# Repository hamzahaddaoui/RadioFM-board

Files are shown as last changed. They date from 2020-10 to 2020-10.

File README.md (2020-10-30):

# Radio FM with speaker

## Abstract

In this project I developed a microcontroller based system that transmits a digital audio signal to an amplifier, attached to a speaker.
The audio signal can be received from different sources such as an FM radio module, which picks up various frequencies, or from a 3.5mm jack. Further development may include a bluetooth support.

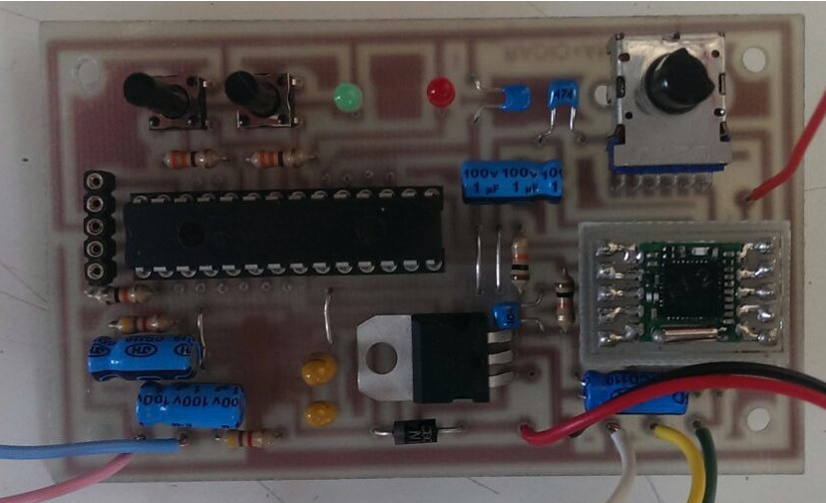
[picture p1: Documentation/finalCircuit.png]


## Details

The project began with a deep study of the TEA5767 chip, and the developing of a library for its usage.
This component is an electronically tuned FM stereo radio for low-voltage applications with fully integrated Intermediate Frequency (IF) selectivity and demodulation. The radio is completely adjustment-free and only requires a minimum of small and low cost external components. The radio can be tuned to the European, US, and Japanese FM bands.

The amplification stage was handled by the PAM8320 which is an efficient 20W mono Class-D audio power amplifier, designed to drive speakers as low as 4Ω in a bridge-tied- load configuration. Due to the low power dissipation and high efficiency of up to 95%, it can be used without any external heat sink whilst playing music.

The microcontroller mounted on the board (8-bit Microchip PIC) controls the user inputs (buttons) and  generates a response to be sent to the radio module. Using the buttons on the top of the speaker, it is possible to change frequency, save favourite stations or go on search mode.

### Schematic 
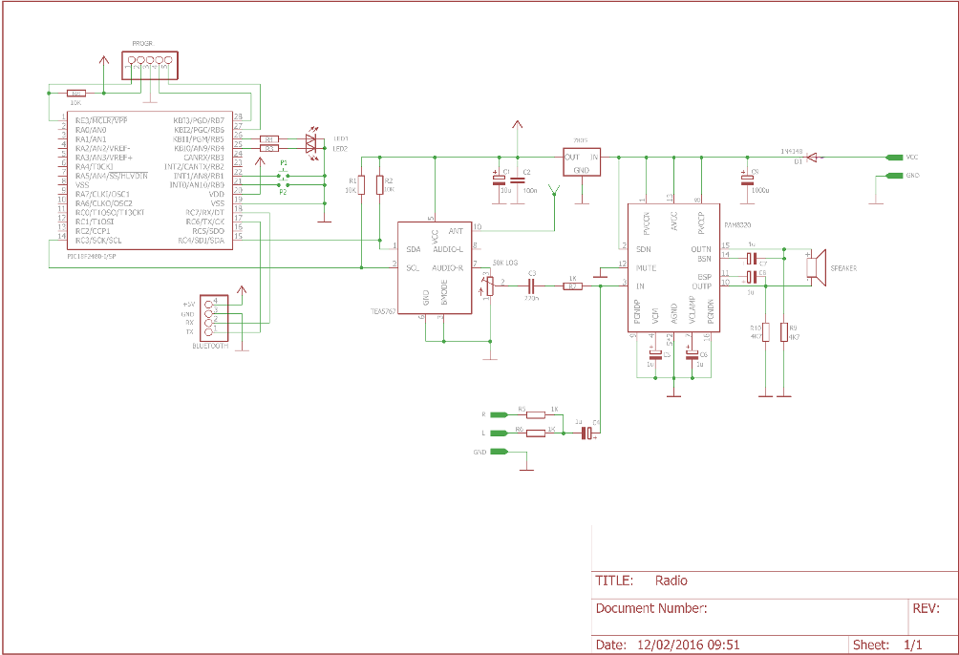
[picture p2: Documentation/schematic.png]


### PCB
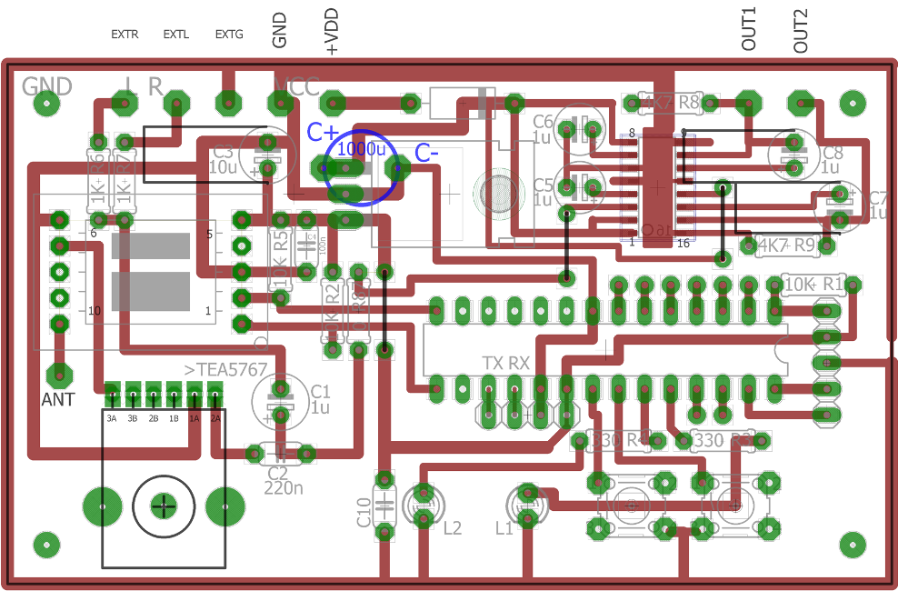
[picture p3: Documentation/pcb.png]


### Board photoengraving process
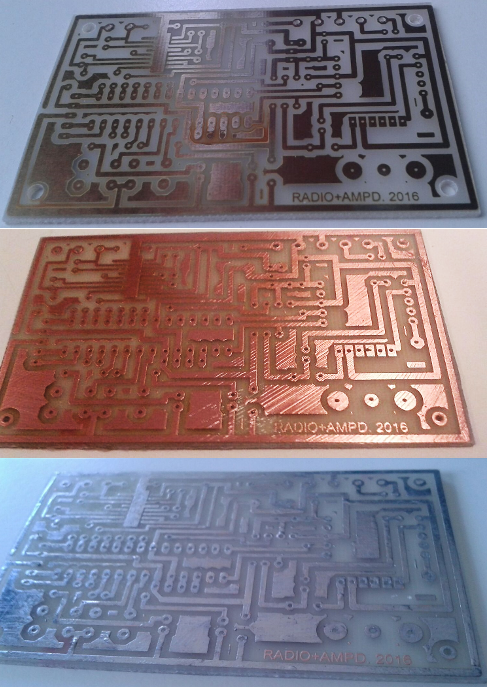
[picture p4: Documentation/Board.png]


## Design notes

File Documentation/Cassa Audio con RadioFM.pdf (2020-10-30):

Cassa Audio con Radio FM

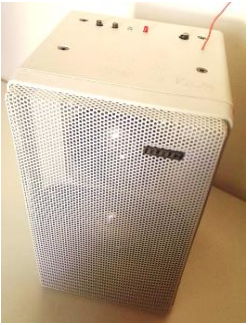
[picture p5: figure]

Hamza Haddaoui | 4ECn | 25/04/16

Hamza Haddaoui
4

a
ECn I.T.I.S. P. Paleocapa
12/02/16

In questo progetto è stato realizzato un dispositivo che permette di amplificare un segnale audio, inviandolo ad una cassa operante in modalità mono.
Il segnale audio, può essere ricevuto da diverse sorgenti quali un modulo radio FM, che provvede a captare frequenze, oppure da un jack 3,5mm.
Il microcontrollore montato sulla scheda, provvede a ricevere gli input, cioè lo stato dei tasti presenti sul pannello superiore, e generare una risposta da inviare al modulo della radio. É possibile cambiare frequenza, o tra quelle salvate oppure in modalità di ricerca.

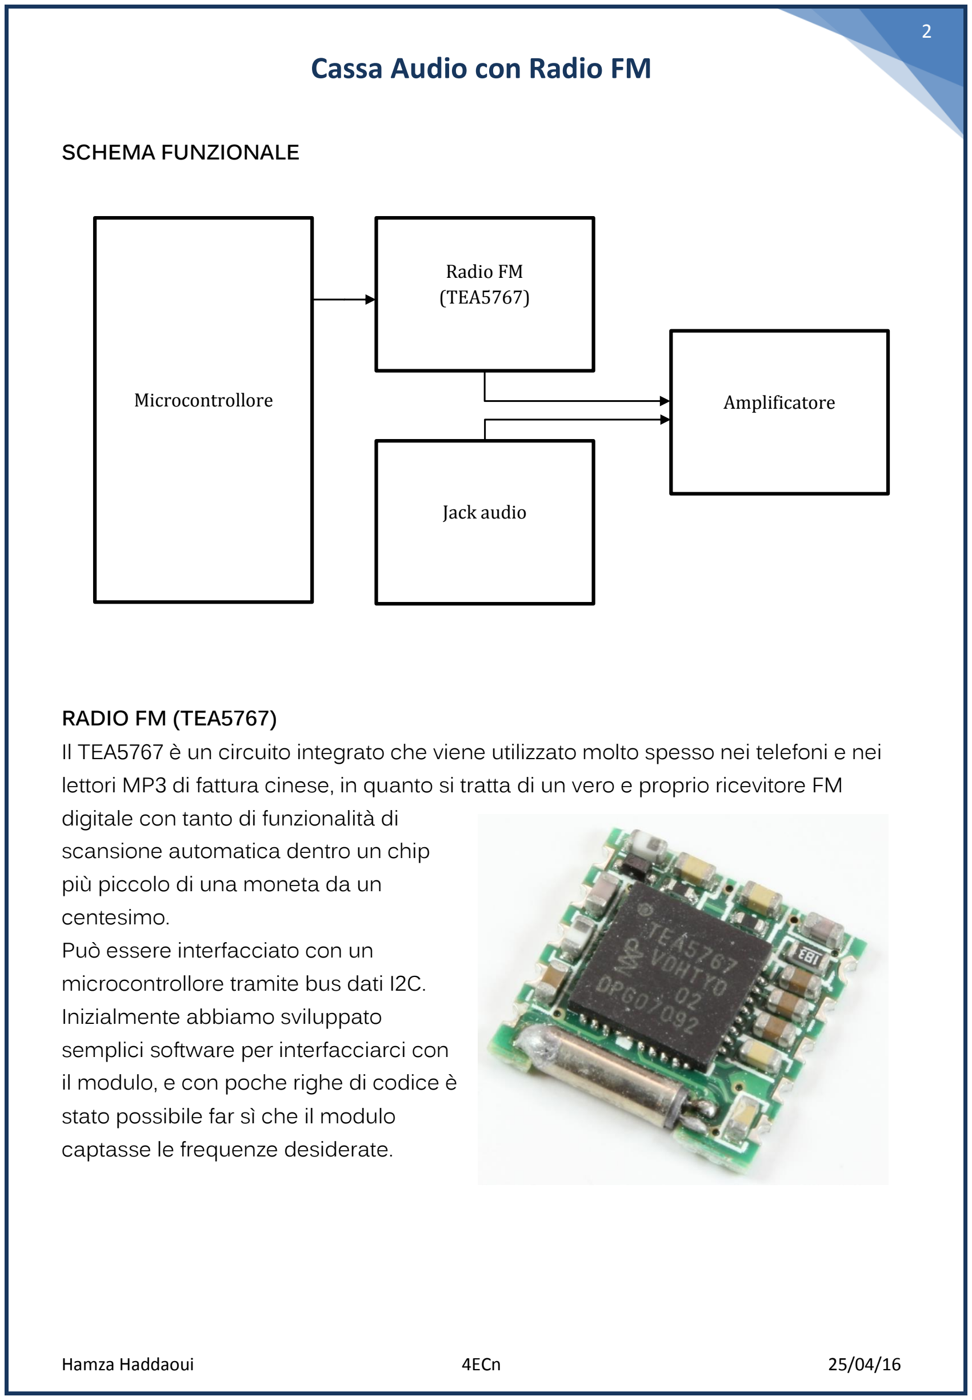
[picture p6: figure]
SCHEMA FUNZIONALE; RADIO FM (TEA5767); digitale con tanto di funzionalità di scansione automatica dentro un chip più piccolo di una moneta da un centesimo. Può essere interfacciato con un microcontrollore tramite bus dati I2C. Inizialmente abbiamo sviluppato semplici software per interfacciarci con; stato possibile far sì che il modulo captasse le frequenze desiderate.; Microcontrollore; Radio FM (TEA5767); Jack audio; Amplificatore

Il TEA5767 è un circuito integrato che viene utilizzato molto spesso nei telefoni e nei lettori MP3 di fattura cinese, in quanto si tratta di un vero e proprio ricevitore FM

il modulo, e con poche righe di codice è

Le funzionalità principali della radio sono:
- Stand-by
- Ricerca automatica
- Signal dependent High Cut Control (HCC)
- Soft mute
- Stereo Noise Cancelling (SNC)
- Informazioni sulla qualità del segnale

Amplificatore (PAM8320)
L’amplificatore è un dispositivo elettronico che varia il segnale in uscita, in funzione di un segnale applicato al suo ingresso al fine di aumentarne la potenza.
Esistono diverse tipologie di amplificatori, che differiscono per qualità di amplificazione, consumo energetico, etc.
Il PAM8320 è un classe D, vale un amplificatore con un’efficienza energetica molto alta (circa 90%) dovuta al fatto che i transistor utilizzati non lavorano mai in zona attiva, ma continuano a commutare da accesi a spenti (sono detti infatti amplificatori a commutazione).
Le caratteristiche principali di questo amplificatore:
Potenza | 20W
Alimentazione | 4.5V – 15V
Impedenza d’uscita | 4 ohm

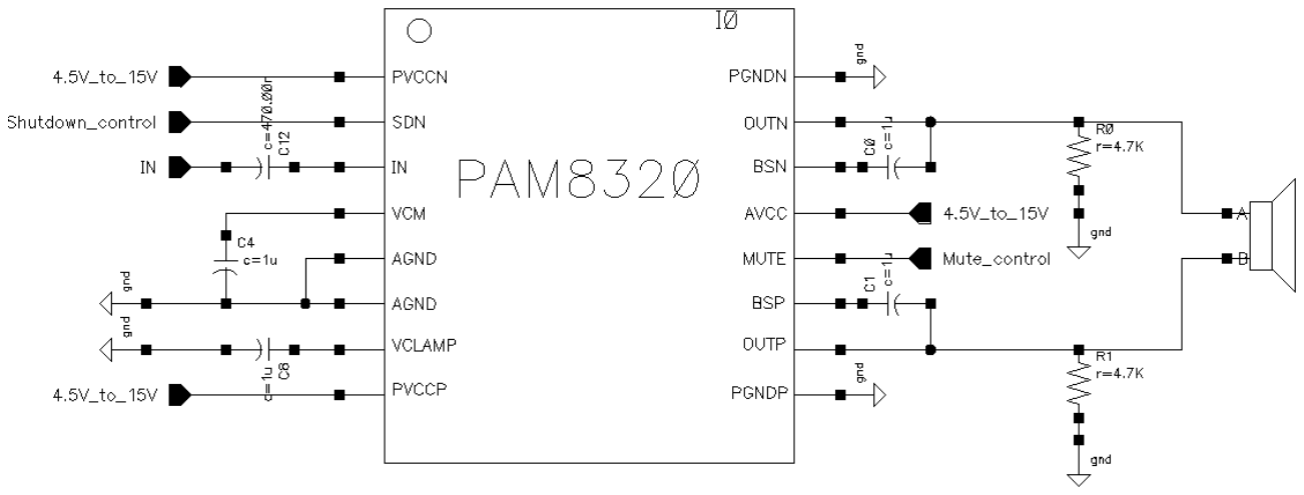
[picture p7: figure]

Fasi di lavoro:
1. Progettazione e realizzazione scheda elettronica
2. Collaudo e programmazione
3. Assemblaggio della cassa audio

PROGETTAZIONE
Nella prima fase, dopo aver studiato i componenti base del progetto (Radio e amplificatore), ci siamo dedicati allo studio dello schema elettrico, e la realizzazione su carta del PCB.
Una volta terminata la parte di disegno,
abbiamo realizzato le schede elettroniche
tramite la tecnica di fotoincisione.
Il punto di partenza, sono state delle basette, interamente ricoperte di rame da un lato, e il disegno del PCB, stampato a grandezza reale su foglio lucido. Mediante l’uso di un bromografo, la basetta viene esposta ai raggi ultravioletti nei punti non coperti dal PCB (vale a dire, dovunque non ci siano piste, piazzole etc.). Dopodiché la basetta viene trattata chimicamente, e vengono eliminati questi punti “ciechi”. Il passaggio successivo è stato quello di eliminare tramite una spazzola abrasiva, tutto il materiale che
copriva il rame, e subito dopo di stagnare
le piste e le piazzole.

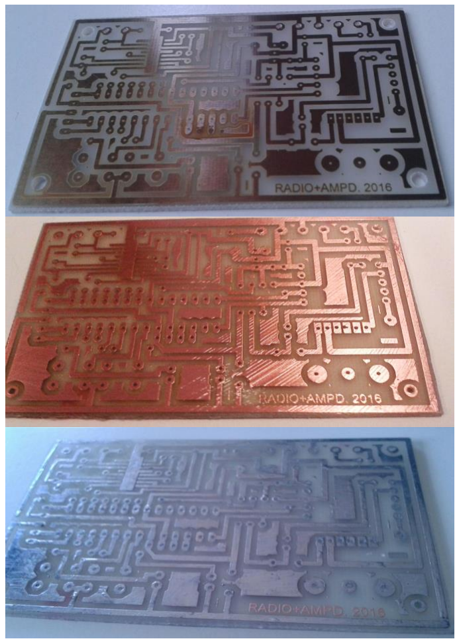
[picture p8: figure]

Una volta fatto ciò, abbiamo montato tutti i componenti, seguendo lo schema fatto precedentemente.

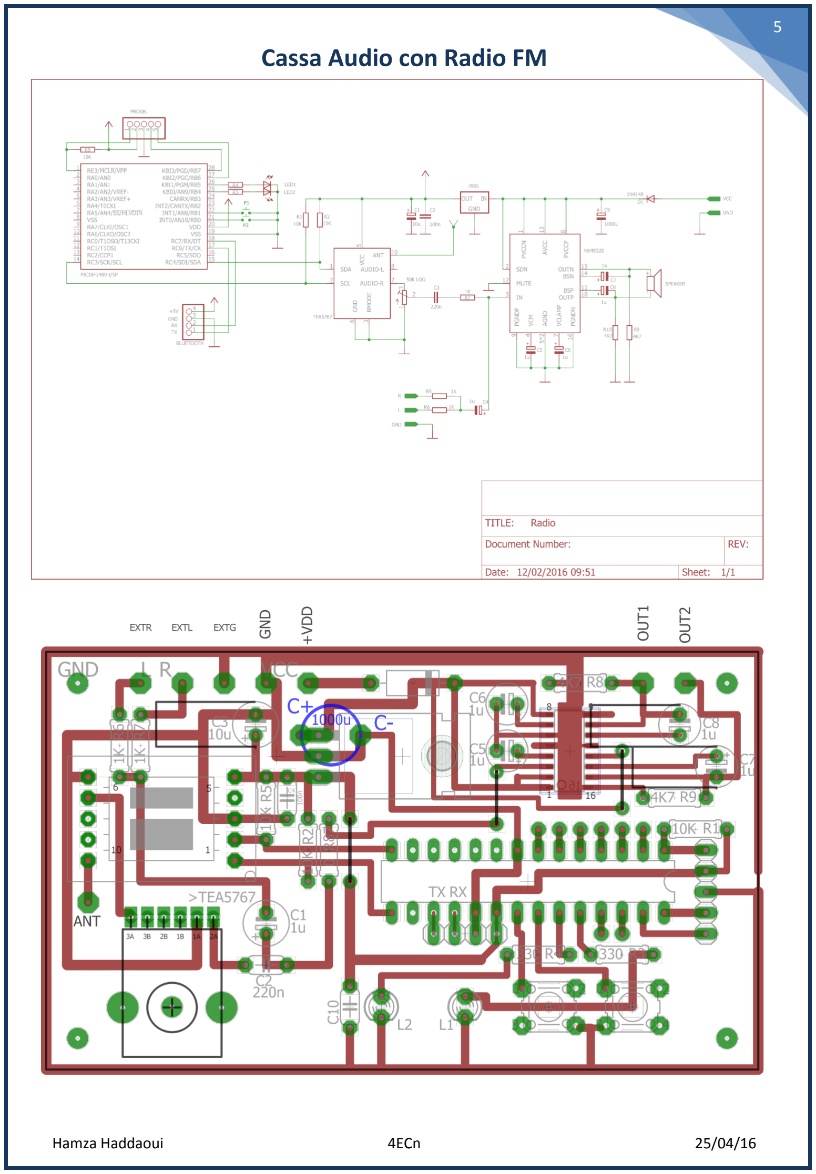
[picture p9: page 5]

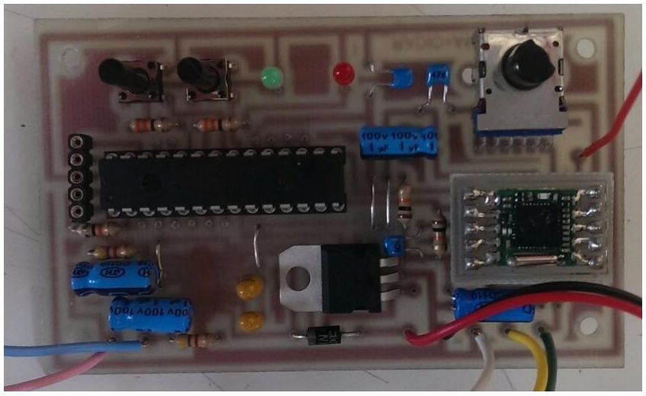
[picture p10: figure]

COLLAUDO E PROGRAMMAZIONE
Per collaudare la scheda abbiamo fatto alcuni test per verificare innanzitutto che non ci fossero corti sulla scheda. Successivamente abbiamo testato il funzionamento dell’amplificatore collegando una sorgente audio dal jack 3,5mm.
Per testare la parte digitale (microcontrollore, radio), è stato necessario caricare un programma di prova, che prima di tutto testasse i pulsanti e i led montati sulla basetta. Successivamente, se tutti i test precedenti erano stati portati a termine con successo, bisognava testare la radio con il programma definitivo.
La programmazione avviene tramite Pickit, collegando la scheda ad esso, tramite la strip a 5 poli, e avendo l’accortezza di togliere i ponticelli di programmazione e alimentazione dal Pickit.
Il microcontrollore utilizzato è un PIC18F2480. Si programma esattamente come un PIC18F4580, tranne per alcune righe di codice, relative alle direttive del preprocessore:

#pragma config OSC=IRCIO7

#pragma config WDT=OFF, PBADEN=OFF, MCLRE=ON, DEBUG=ON, LVP=OFF

ASSEMBLAGGIO CASSA AUDIO
Terminata la programmazione del microcontrollore, abbiamo aperto la cassa audio. Successivamente abbiamo praticato nel contenitore dei fori, sia per fissare la scheda elettronica, che per far fuoriuscire i tasti, i led il potenziometro e il jack audio. Terminata questa parte, abbiamo montato la scheda elettronica, tramite distanziali e viti nella parte alta del contenitore.

Lista componenti utilizzati
Componente | Qtà
Altoparlante 40W – 4ohm | 1
7805 | 1
TEA5767 | 1
PAM8320 | 1
Trimmer logaritmico | 1
PIC18F2480 | 1
Led, resistenze e condensatori vari | -
Zoccolo a 5/4/28 pin | 3

Note finali
Con questo progetto ho acquisito conoscenze nell’ambito audio, e nell’ambito degli amplificatori. Ho compreso meglio il funzionamento dell’interfaccia I2C.
In futuro è prevista un’espansione del progetto con un modulo bluetooth, per impartire comandi alla radio, tramite uno smartphone o un PC.

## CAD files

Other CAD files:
src/Cassa_Audio.obj
src/startup.obj

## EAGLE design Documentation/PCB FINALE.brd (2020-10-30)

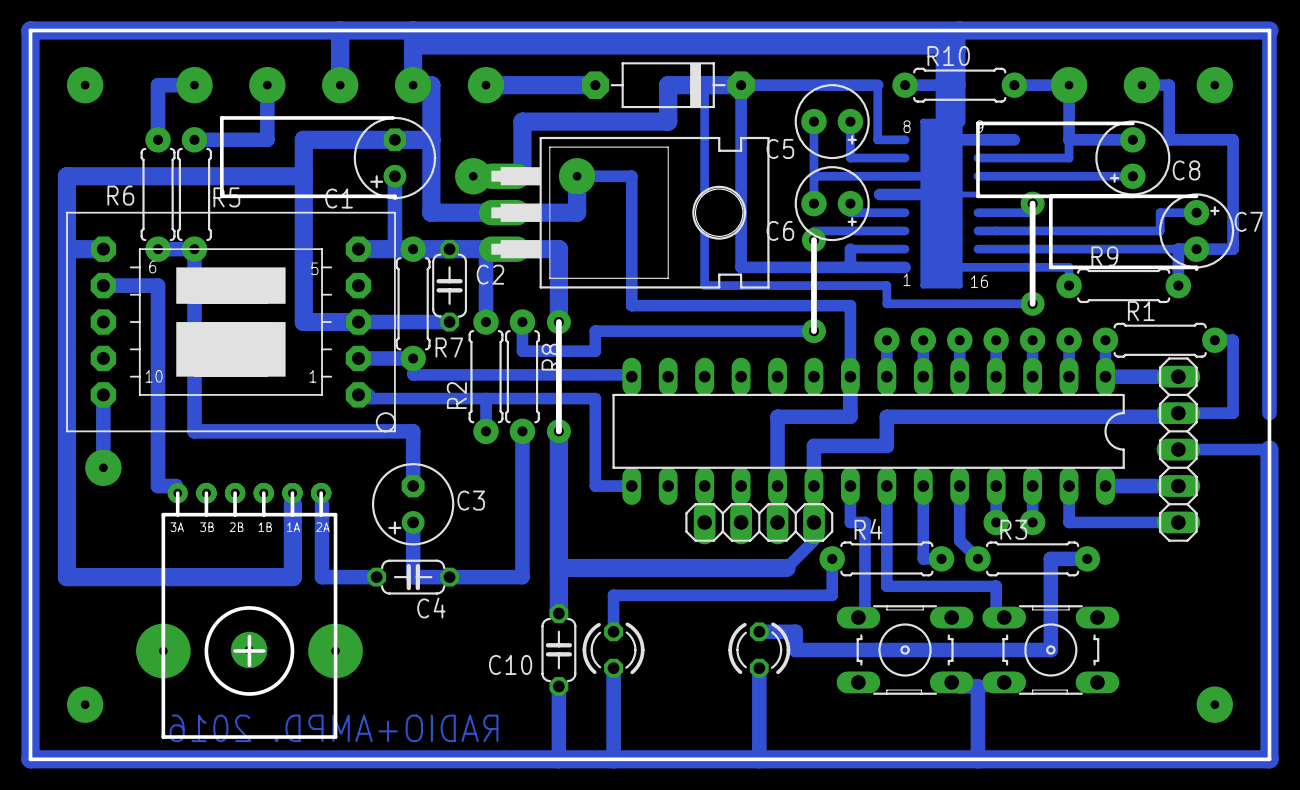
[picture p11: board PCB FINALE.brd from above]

Board: 2 copper layers, 86.4 x 50.8 mm, 30 parts (1 on the bottom side), 18 nets.

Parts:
C1: 10u; E2,5-6
C2, C10: 100n; C050-024X044
C3: 200u; E2,5-6
C4: 1u; C050-024X044
C5, C6, C7, C8: 1u; E2,5-5
E$1: SO-16
E$3: TO220H
E$4: TEA5767
E$5: D-10
E$6: DIL28-3
E$7: 1X05
E$8: 1X04
L1, L2: LED3MM
R1, R2, R7: 10K; 0207/7
R3, R4: 330; 0207/7
R5, R6, R8: 1K; 0207/7
R9: 4k7; 0207/7
R10: 4K7; 0207/7
T1, T2: B3F-10XX

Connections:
S$7: E$6.28, E$7.2
S$8: E$6.27, E$7.1
S$9: E$4.1, E$6.15, R2.1
S$10: E$4.2, E$6.14, R7.2
S$11: C3.-, R5.1, R6.1
S$12: C3.+, C4.2, R8.2
S$21: E$6.24, R3.1
S$22: L1.A, R3.2
S$24: E$6.23, R4.2
S$25: L2.A, R4.1
S$27: C1.+, C2.1, E$3.3, E$4.5, R2.2, R7.1, R8.1
S$33: C1.-, C2.2, C10.1, E$3.2, E$4.3, E$4.6, E$6.8, E$6.19, E$7.3, E$8.3, L1.K, L2.K, R9.1, R10.1
S$49: E$6.17, E$8.1
S$50: E$6.18, E$8.2
S$51: C10.2, E$6.20, E$7.4, E$8.4, R1.2
S$54: C8.-, R10.2
S$55: E$6.1, E$7.5, R1.1
S$72: E$3.1, E$5.C

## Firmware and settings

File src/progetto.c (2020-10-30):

#include <htc.h>
#pragma config OSC=IRCIO7 
#pragma config WDT=OFF, PBADEN=OFF, MCLRE=ON, DEBUG=ON, LVP=OFF
#define _XTAL_FREQ 8MHZ 										//definizione necessaria alla <delay.c>
#define FREQMHZ 8												//per i2c.c
#include "i2c.c"
#include "TEA5767.c"
//#include "EEPROM.c"

/****************************************************************
CODICI RELATIVI ALLE VARIE POSSIBILI INTERAZIONI CON I 2 TASTI
****************************************************************/
#define bothButtons 	0x10
#define button1Long  	0x11
#define button1Short	0x12
#define button2Long		0x13
#define button2Short 	0x14

void setup(void);
char detectButton(void);
void functionsRoutine(void);

unsigned char function=0;	//Memorizza il codice relativo alla tipologia di interazione
bit smode;					//Search MODE attiva? 1 - SI , 0 - NO
bit status; 				//Radio attiva? 1 - SI , 0 - NO
					
void main(){
	unsigned char prevFunction;
	setup();
	while(1){
		while(detectButton() == 0);
		functionsRoutine();
	}
}

/********************************************
*  FUNZIONE SETUP							*
*  Settaggio parametri base.				*
*********************************************/
void setup(void){
	ADCON1=0x0F;
	OpenI2C_StSpeed();
	OSCCON= 0b01110000;			//8MHZ
	TRISB =	0b11110011;			//RB2-RB3 OUTPUT
	RBPU = 1;					//Attivo PULL-UP su PORTB
	LATB0= 1;					//Set alto degli ingressi RB0-RB1
	LATB1= 1;
	TEA_setFreq(10250);
	TEA_cmd(HLSI,1);
	TEA_cmd(MS,1);
	TEA_cmd(SMUTE,1);
	TEA_cmd(HCC,1);
	TEA_cmd(HLSI,1);
	TEA_cmd(SNC,1);
	TEA_cmd(XTAL,1);
	TEA_cmd(SSL,1);
}

/********************************************
*  FUNZIONE functionsRoutine				*
*  Controlla la funzione invocata tramite 	*
*  i tasti, e ne svolge le istruzioni 		*
*  relative									*
*********************************************/
void functionsRoutine(void){
	switch(function){
		case 0x10:								//bothButtons -> SPEGNI/ACCENDI RADIO
			status^=1;
			TEA_cmd(STBY,status);
			break;
		case 0x11:								//button1Long -> SMODE ON/OFF
			smode^=1;
			break;
		case 0x12:								//button1Short -> CANALE PRECEDENTE
			if (smode){
				TEA_setFreq(0);
			} 
			else{
				TEA_setFreq(8830);
			}
			break;
		case 0x13:								//button2Long -> SALVATAGGIO FREQ(Smode)  to do!
			break;
		case 0x14:								//button2Short -> CANALE SUCCESSIVO	
			if (smode){
				TEA_setFreq(1);
			}
			else{
				TEA_setFreq(10250);
			}
		default:
			break;	
		}
	function=0;
	_delay(150000);
	_delay(150000);
	_delay(150000);
}

/********************************************
*  FUNZIONE detectButton					*
*  Provvede a controllare lo stato dei		*
*  pulsanti, e rilevare le 5 possibili 		*
*  modalità di interazione					*
*********************************************/
char detectButton(void){
	char q;
	if (RB0 || RB1){
		_delay(100000);
		if(RB0&&RB1){							//PRESSIONE BREVE TASTO1 & TASTO2
			function=0x10;
		}
		else if (RB0){ 															
			for(q=0;q<4;q++) _delay(150000);
			if(RB0){							//PRESSIONE PROLUNGATA TASTO1
				function=0x11;
			}
			else{								//PRESSIONE BREVE TASTO1
				function=0x12;
			}											
		}	
		else if (RB1){
			for(q=0;q<4;q++) _delay(150000);
			if(RB1){							//PRESSIONE PROLUNGATA TASTO2
				function=0x13;
			}
			else{								//PRESSIONE BREVE TASTO2
				function=0x14;
			}
		}
		else{
			function=0;	
		} 
	}
	else{
		function=0;	
	} 
	return function;
}

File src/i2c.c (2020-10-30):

//=============================================================================
// funzioni I2C

#include <htc.h> 

#define I2C_SCL	TRISCbits.TRISC3
#define I2C_SDA	TRISCbits.TRISC4

/*******************************************************************
Macro       : StopI2C()
Remarks     : This macro initiates stop condition and waits till the stop signal
		sequence is terminated.This macro is applicable only to master
*******************************************************************/
#define StopI2C()  SSPCON2bits.PEN=1;while(SSPCON2bits.PEN)

/*******************************************************************
Macro       : StartI2C()
Remarks     : This macro initiates start condition and waits till the start signal
		sequence is terminated. This macro is applicable only to master
*******************************************************************/
#define StartI2C()  SSPCON2bits.SEN=1;while(SSPCON2bits.SEN)

/*******************************************************************
Macro       : RestartI2C()
Remarks     : This macro initiates Restart condition and waits till the Restart signal
		sequence is terminated. This macro is applicable only to master
*******************************************************************/
#define RestartI2C()  SSPCON2bits.RSEN=1;while(SSPCON2bits.RSEN)

/*******************************************************************
Macro       : NotAckI2C()
Remarks     : This macro initiates negetive acknowledgement condition and 
		waits till the acknowledgement sequence is terminated.
		This macro is applicable only to master
*******************************************************************/
#define NotAckI2C()     SSPCON2bits.ACKDT=1;SSPCON2bits.ACKEN=1;while(SSPCON2bits.ACKEN)

/*******************************************************************
Macro       : AckI2C()
Remarks     : This macro initiates positive acknowledgement condition and 
		waits till the acknowledgement sequence is terminated.
		This macro is applicable only to master
*******************************************************************/
#define AckI2C()        SSPCON2bits.ACKDT=0;SSPCON2bits.ACKEN=1;while(SSPCON2bits.ACKEN)

/************************************************************************
Macro :  DataRdyI2C() 
Remarks            : This Macro determines if there is any byte to read from
			SSPxBUF register.
*************************************************************************/
#define DataRdyI2C()    (SSPSTATbits.BF)


/**********************************************************************************************
Function Prototype : void IdleI2C(void) 
Remarks            : This function will be in a wait state until Start Condition Enable bit,
                     Stop Condition Enable bit, Receive Enable bit, Acknowledge Sequence
                     Enable bit of I2C Control register and Transmit Status bit I2C Status
                     register are clear. The IdleI2C function is required since the hardware
                     I2C peripheral does not allow for spooling of bus sequence. The I2C
                     peripheral must be in Idle state before an I2C operation can be initiated
                     or write collision will be generated.
***********************************************************************************************/
void IdleI2C( void )
{
  while ( ( SSPCON2 & 0x1F ) || ( SSPSTATbits.R_W ) )
     continue;
}


/*********************************************************************
Function Prototype : void CloseI2C(void)
Remarks            : This function disables the I2C module and clears the
			I2C Interrupt Enable and Flag bits.
*********************************************************************/
void CloseI2C( void )
{
  SSPCON1 &= 0xDF;                // disable synchronous serial port
}


/********************************************************************
*   Function Name:  OpenI2C                                         *
*   Return Value:   void                                            *
*   Parameters:     SSP peripheral setup bytes                      *
*   Description:    This function sets up the SSP module on a       * 
*                   PIC18CXXX device for use with a Microchip I2C   *
*                   EEPROM device or I2C bus device.                *
********************************************************************/

/*
void OpenI2C( unsigned char sync_mode, unsigned char slew )
{
  SSPSTAT &= 0x3F;                // power on state 
  SSPCON1 = 0x00;                 // power on state
  SSPCON2 = 0x00;                 // power on state
  SSPCON1 |= sync_mode;           // select serial mode 
  SSPSTAT |= slew;                // slew rate on/off 

  I2C_SCL = 1;
  I2C_SDA = 1;
  SSPCON1 |= SSPENB;              // enable synchronous serial port 

}
*/

void OpenI2C_StSpeed()            // clock 100KHz
{
  SSPSTAT &= 0x3F;                // power on state 
  SSPCON1 = 0x08;                 // power on state + MASTER mode
  SSPCON2 = 0x00;                 // power on state
  SSPSTAT |= 0x80;                // slew rate disable (100KHz, 1MHz) 

// clock=FOSC/(4*SSPADD+1)
// SSPADD= (FOSC*10)/4 -1
	SSPADD=9;						//default	
   #if FREQMHZ == 4 
         SSPADD=9;
   #elif FREQMHZ == 8
         SSPADD=19;		
   #elif FREQMHZ == 16
         SSPADD=39;
   #elif FREQMHZ == 32
         SSPADD=79;
   #endif

  I2C_SCL = 1;
  I2C_SDA = 1;
  SSPCON1 |= 0x20;                // enable synchronous serial port 

}


/********************************************************************
*     Function Name:    ReadI2C                                     *
*     Return Value:     contents of SSPBUF register                 *
*     Parameters:       void                                        *
*     Description:      Read single byte from I2C bus.              *
********************************************************************/

unsigned char ReadI2C( void )
{
if( ((SSPCON1&0x0F)==0x08) || ((SSPCON1&0x0F)==0x0B) )	//master mode only
  SSPCON2bits.RCEN = 1;           // enable master for 1 byte reception
  while ( !SSPSTATbits.BF );      // wait until byte received  
  return ( SSPBUF );              // return with read byte 
}

/********************************************************************
*     Function Name:    WriteI2C                                    *
*     Return Value:     Status byte for WCOL detection.             *
*     Parameters:       Single data byte for I2C bus.               *
*     Description:      This routine writes a single byte to the    * 
*                       I2C bus.                                    *
********************************************************************/
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
